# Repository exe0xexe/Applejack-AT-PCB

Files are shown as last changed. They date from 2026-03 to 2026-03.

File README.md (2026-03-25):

# PCB for converting AT layout keyboards to MX
### Powered by QMK/VIAL
## Layout





## Bill Of Materials 

### To build the keyboard, you will need the following materials
- 1x STM32F401CCU6 Blackpill
- Pins and sockets for the microcontrollers (blackpill needs 20 pin stripes)
- 98 1N4148 DO-35 diodes
- 22 Wire jumpers (you can use diode legs) 
- 4 82ohm resistors (optional)
- LED (optional)

## Completed build 

photo_2025-09-02_19-01-52 (2)



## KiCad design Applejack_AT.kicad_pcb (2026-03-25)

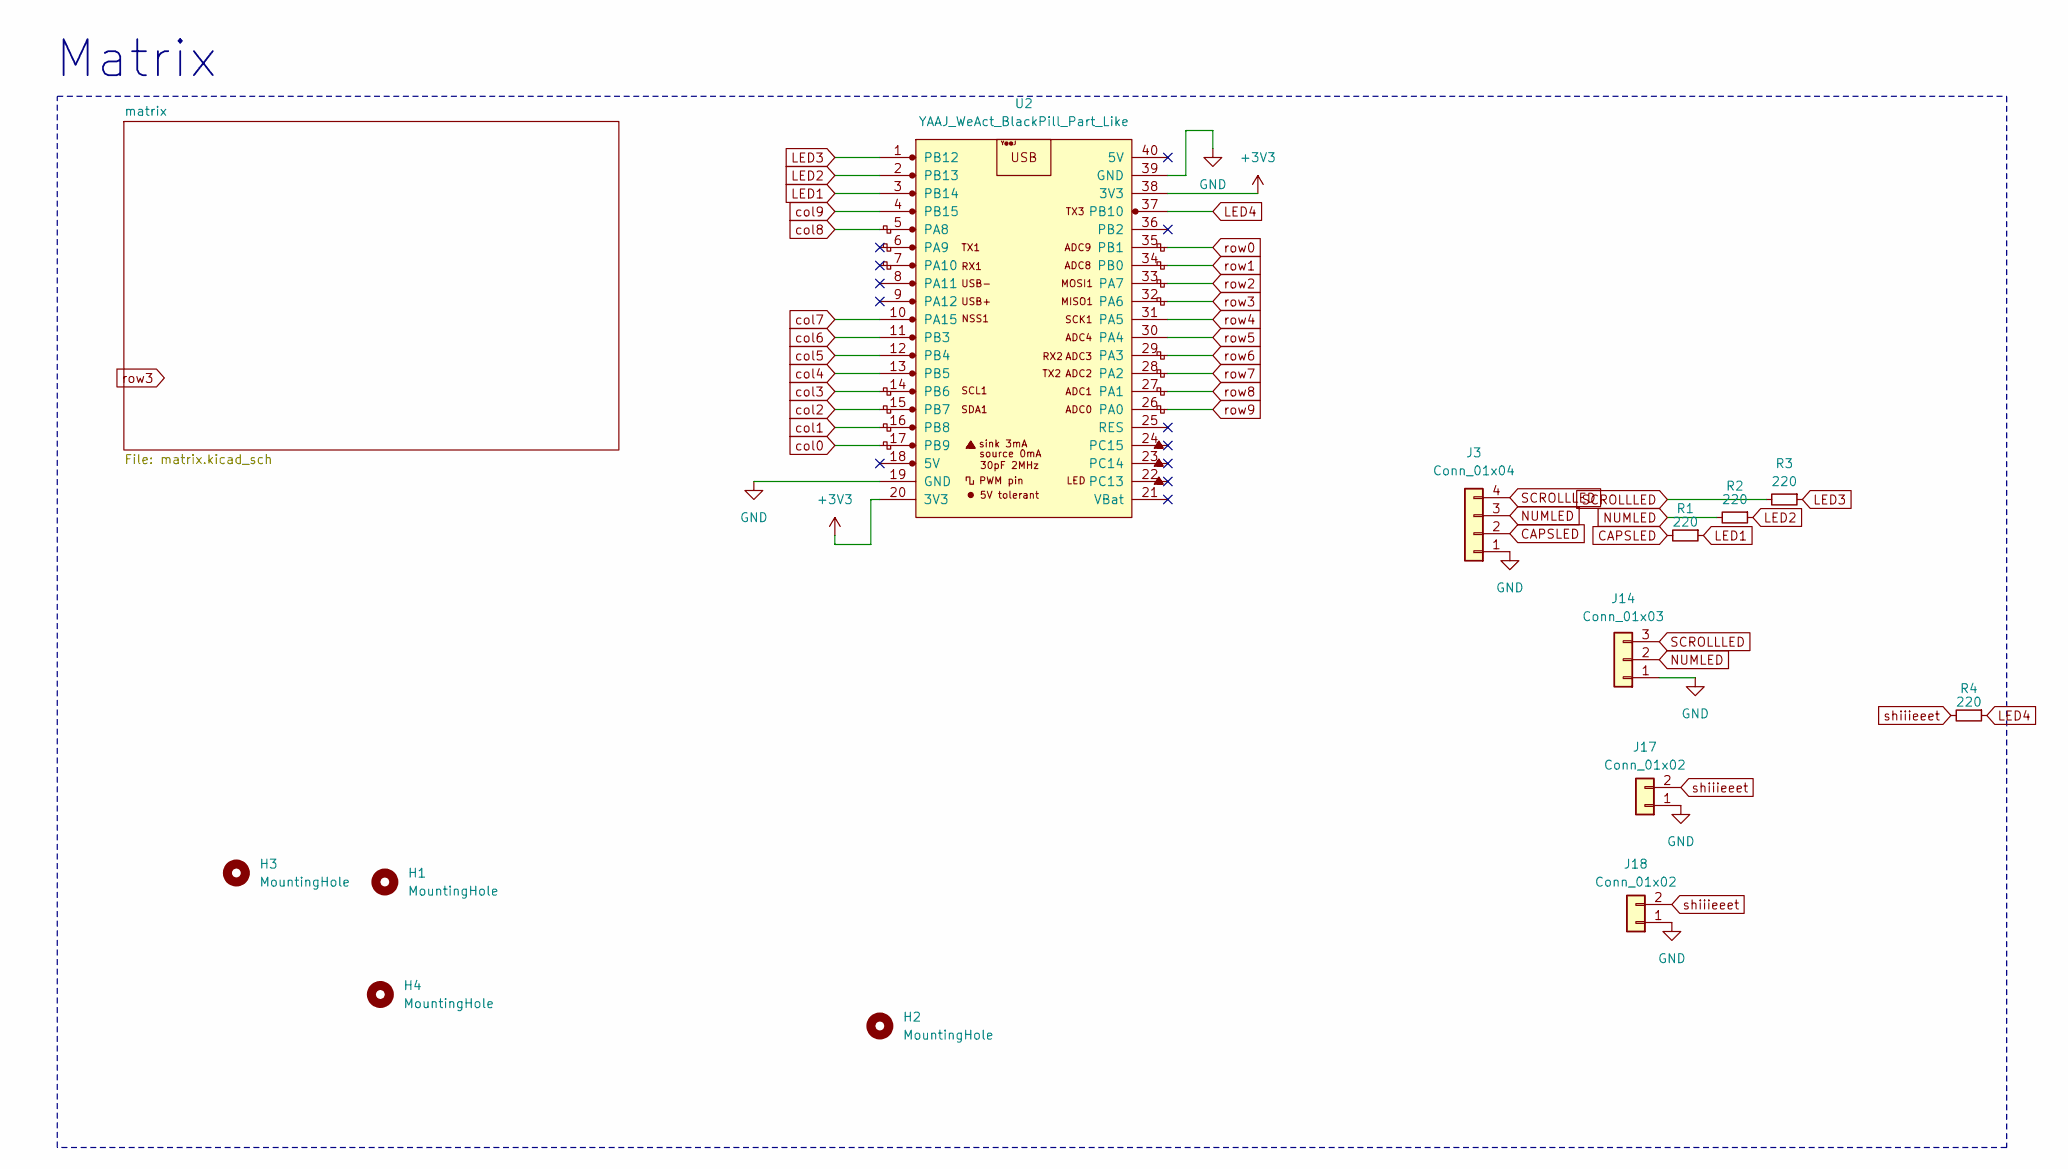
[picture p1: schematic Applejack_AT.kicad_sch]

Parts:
H1, H2, H3, H4: MountingHole; mousebites_2.5mm_4p
J3: Conn_01x04; PinHeader_1x04_P2.54mm_Horizontal
J14: Conn_01x03; 3pin
J17, J18: Conn_01x02; 2pin-GND
R1, R2, R3, R4: 220; R_Axial_DIN0207_L6.3mm_D2.5mm_P7.62mm_Horizontal_no_silkscr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
U2: YAAJ_WeAct_BlackPill_Part_Like; YAAJ_WeAct_BlackPill_2_twilight_sparkle_no_cut

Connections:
+3V3: U2.20 (3V3), U2.38 (3V3)
CAPSLED: J3.2, R1.2; also elsewhere on the board
GND: J3.1, J14.1, J17.1, J18.1, U2.19 (GND), U2.39 (GND); also elsewhere on the board
LED1: R1.1, U2.3 (PB14)
LED2: R2.1, U2.2 (PB13)
LED3: R3.1, U2.1 (PB12)
LED4: R4.1, U2.37 (PB10)
NUMLED: J3.3, J14.2, R2.2; also elsewhere on the board
SCROLLLED: J3.4, J14.3, R3.2; also elsewhere on the board
col0: U2.17 (PB9); also elsewhere on the board
col1: U2.16 (PB8); also elsewhere on the board
col2: U2.15 (PB7); also elsewhere on the board
col3: U2.14 (PB6); also elsewhere on the board
col4: U2.13 (PB5); also elsewhere on the board
col5: U2.12 (PB4); also elsewhere on the board
col6: U2.11 (PB3); also elsewhere on the board
col7: U2.10 (PA15); also elsewhere on the board
col8: U2.5 (PA8); also elsewhere on the board
col9: U2.4 (PB15); also elsewhere on the board
row0: U2.35 (PB1); also elsewhere on the board
row1: U2.34 (PB0); also elsewhere on the board
row2: U2.33 (PA7); also elsewhere on the board
row3: U2.32 (PA6); also elsewhere on the board
row4: U2.31 (PA5); also elsewhere on the board
row5: U2.30 (PA4); also elsewhere on the board
row6: U2.29 (PA3); also elsewhere on the board
row7: U2.28 (PA2); also elsewhere on the board
row8: U2.27 (PA1); also elsewhere on the board
row9: U2.26 (PA0); also elsewhere on the board
shiiieeet: J17.2, J18.2, R4.2; also elsewhere on the board

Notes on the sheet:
Matrix

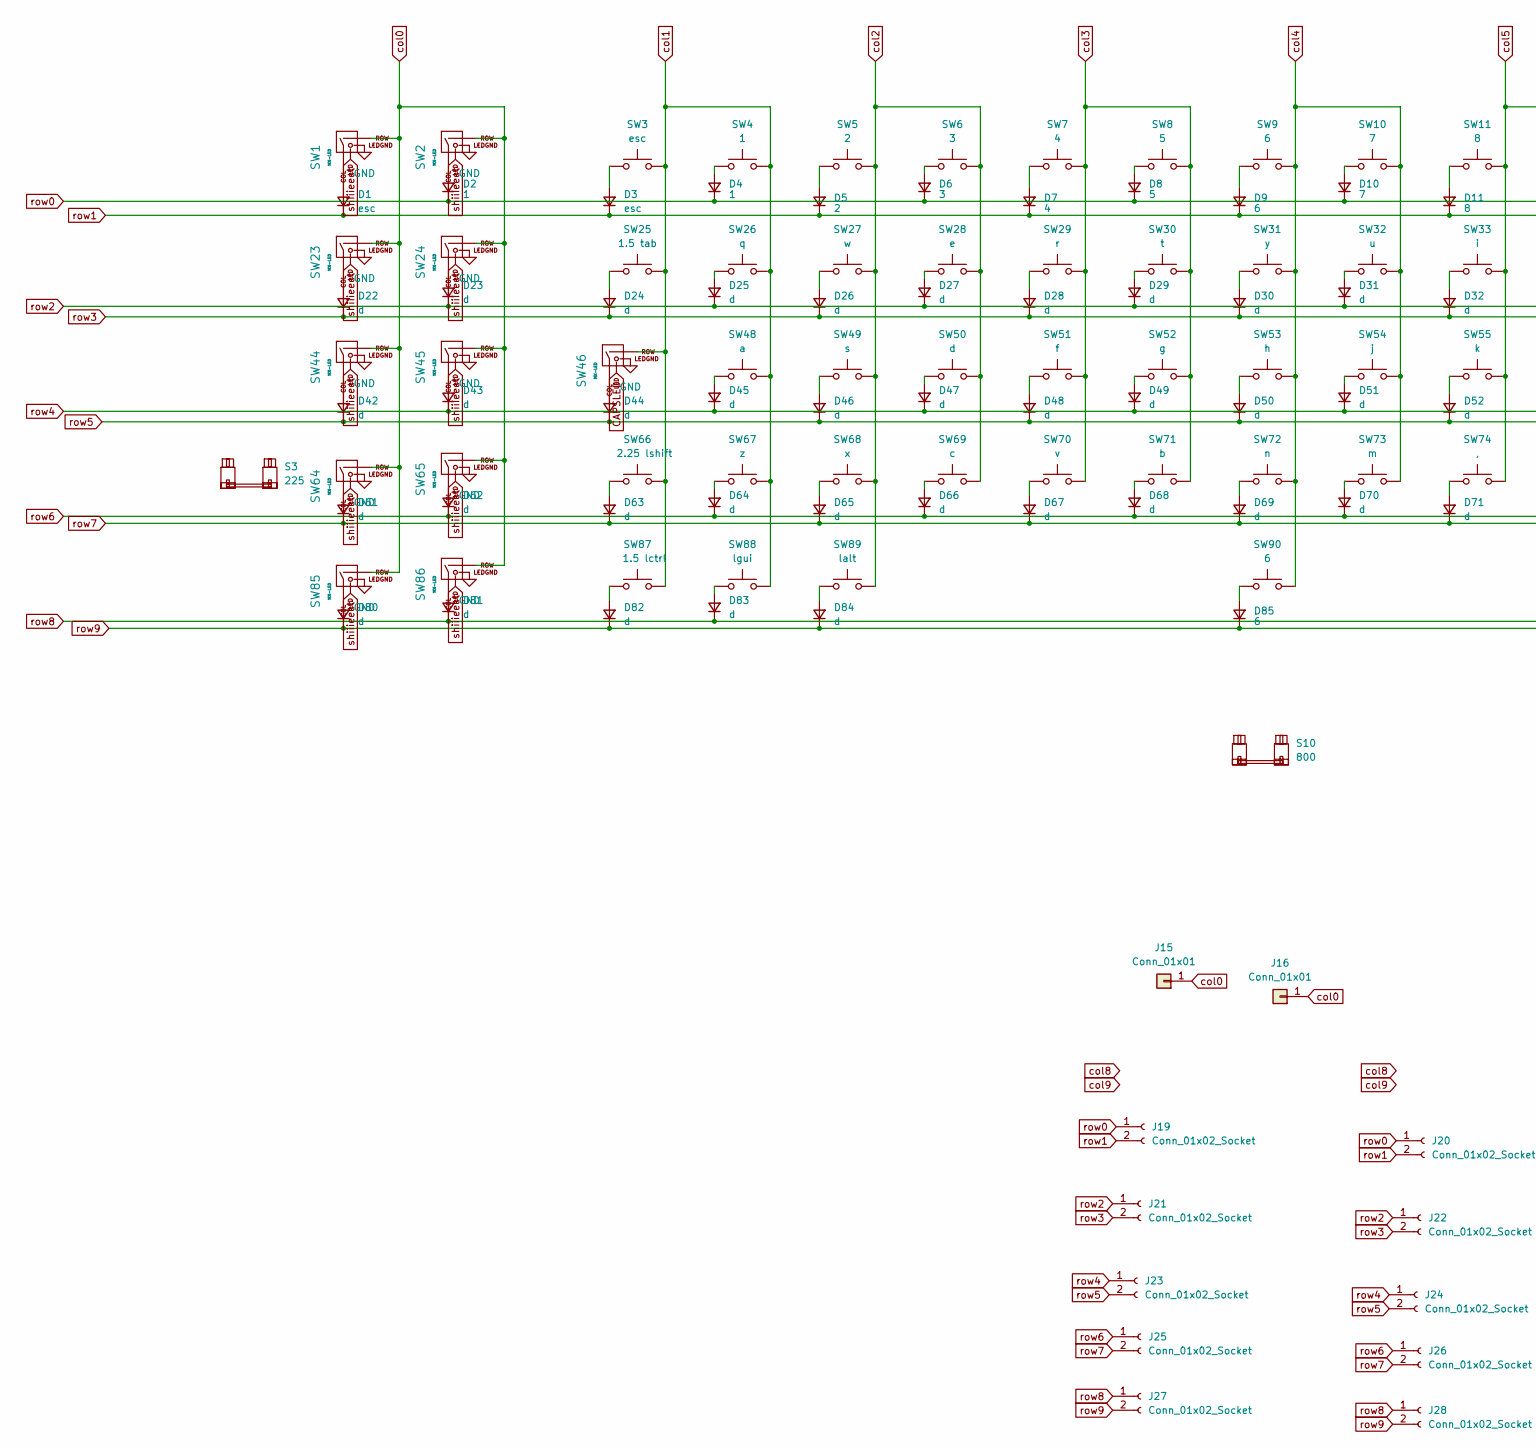
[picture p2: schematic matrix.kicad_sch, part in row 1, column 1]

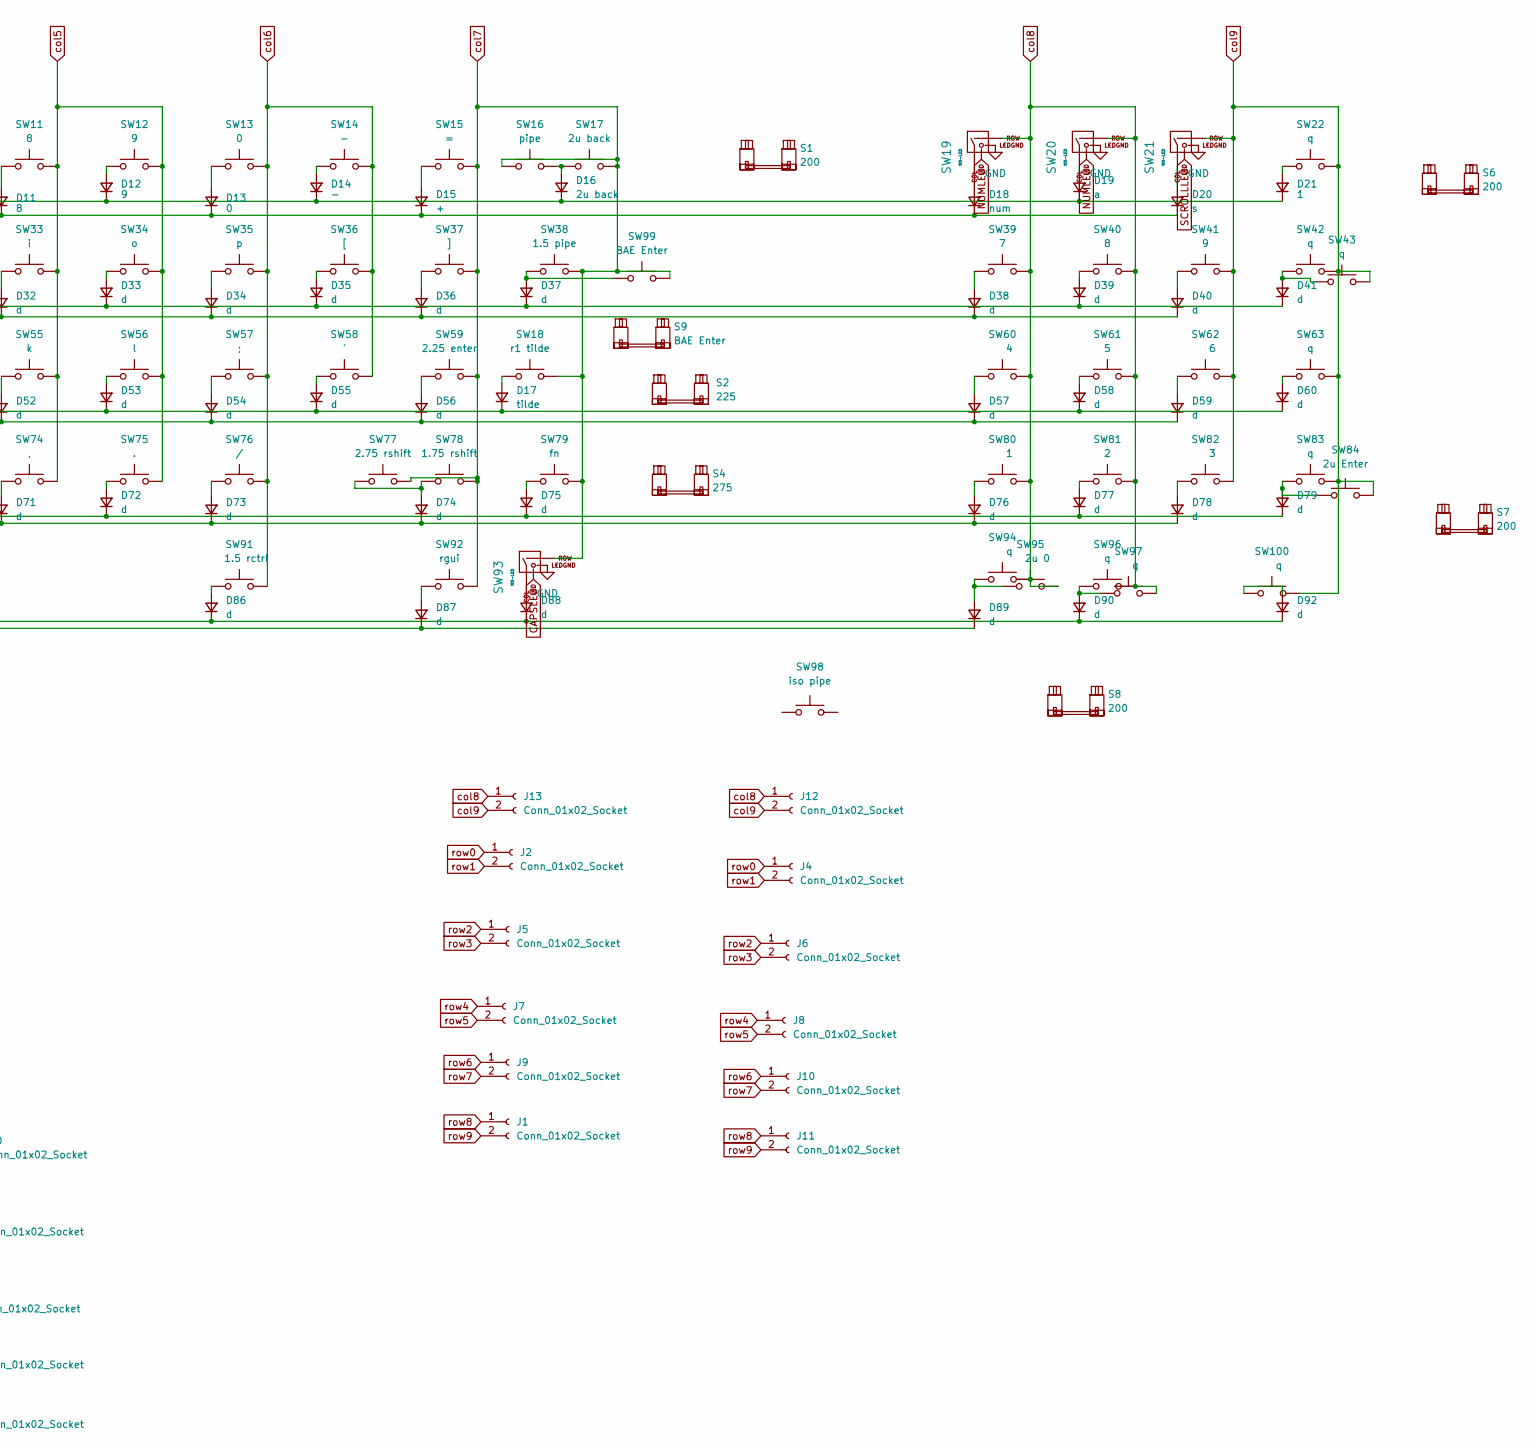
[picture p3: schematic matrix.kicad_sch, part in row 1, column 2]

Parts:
D1, D3: esc; Diode_DO-35
D2, D4, D21: 1; Diode_DO-35
D5: 2; Diode_DO-35
D6: 3; Diode_DO-35
D7: 4; Diode_DO-35
D8: 5; Diode_DO-35
D9, D85: 6; Diode_DO-35
D10: 7; Diode_DO-35
D11: 8; Diode_DO-35
D12: 9; Diode_DO-35
D13: 0; Diode_DO-35
D14: -; Diode_DO-35
D15: +; Diode_DO-35
D16: 2u back; Diode_DO-35
D17: tilde; Diode_DO-35
D18: num; Diode_DO-35
D19: a; Diode_DO-35
D20: s; Diode_DO-35
D22, D23, D24, D25, D26, D27, D28, D29, D30, D31, D32, D33, D34, D35, D36, D37, D38, D39, D40, D41, D42, D43, D44, D45, D46, D47, D48, D49, D50, D51, D52, D53, D54, D55, D56, D57, D58, D59, D60, D61, D62, D63, D64, D65, D66, D67, D68, D69, D70, D71, D72, D73, D74, D75, D76, D77, D78, D79, D80, D81, D82, D83, D84, D86, D87, D88, D89, D90, D92: d; Diode_DO-35
J1, J2, J4, J5, J6, J7, J8, J9, J10, J11, J12, J13, J19, J20, J21, J22, J23, J24, J25, J26, J27, J28: Conn_01x02_Socket; 2pin
J15, J16: Conn_01x01; 1pin
S1, S6, S7, S8: 200; STAB_MX_2u
S2, S3: 225; STAB_MX_2.25u
S4: 275; STAB_MX_2.75u
S9: BAE Enter; STAB_MX_ISO
S10: 800; STAB_MX_10u
SW1, SW2, SW19, SW20, SW21, SW23, SW24, SW44, SW45, SW64, SW65, SW85, SW86, SW93: MX-LED; MX_1U_LED
SW3: esc; MX_1U
SW4, SW80: 1; MX_1U
SW5, SW81: 2; MX_1U
SW6, SW82: 3; MX_1U
SW7, SW60: 4; MX_1U
SW8, SW61: 5; MX_1U
SW9, SW62, SW90: 6; MX_1U
SW10, SW39: 7; MX_1U
SW11, SW40: 8; MX_1U
SW12, SW41: 9; MX_1U
SW13: 0; MX_1U
SW14: -; MX_1U
SW15: =; MX_1U
SW16: pipe; MX_1U
SW17: 2u back; MX_1U
SW18: r1 tilde; MX_1U
SW22, SW26, SW42, SW43, SW63, SW83, SW94, SW96, SW97, SW100: q; MX_1U
SW25: 1.5 tab; MX_1U
SW27: w; MX_1U
SW28: e; MX_1U
SW29: r; MX_1U
SW30: t; MX_1U
SW31: y; MX_1U
SW32: u; MX_1U
SW33: i; MX_1U
SW34: o; MX_1U
SW35: p; MX_1U
SW36: [; MX_1U
SW37: ]; MX_1U
SW38: 1.5 pipe; MX_1U
SW46: MX-LED; MX_CAPS
SW48: a; MX_1U
SW49: s; MX_1U
SW50: d; MX_1U
SW51: f; MX_1U
SW52: g; MX_1U
SW53: h; MX_1U
SW54: j; MX_1U
SW55: k; MX_1U
SW56: l; MX_1U
SW57: ;; MX_1U
SW58: '; MX_1U
SW59: 2.25 enter; MX_1U
SW66: 2.25 lshift; MX_1U
SW67: z; MX_1U
SW68: x; MX_1U
SW69: c; MX_1U
SW70: v; MX_1U
SW71: b; MX_1U
SW72: n; MX_1U
SW73: m; MX_1U
SW74: ,; MX_1U
SW75: .; MX_1U
SW76: /; MX_1U
SW77: 2.75 rshift; MX_1U
SW78: 1.75 rshift; MX_1U
SW79: fn; MX_1U
SW84: 2u Enter; MX_1U
SW87: 1.5 lctrl; MX_1U
SW88: lgui; MX_1U
SW89: lalt; MX_1U
SW91: 1.5 rctrl; MX_1U
SW92: rgui; MX_1U
SW95: 2u 0; MX_1U
SW98: iso pipe; MX_1U
SW99: BAE Enter; MX_1U

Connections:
CAPSLED: SW46.3 (LED), SW93.3 (LED); also elsewhere on the board
GND: SW1.4 (LEDGND), SW2.4 (LEDGND), SW19.4 (LEDGND), SW20.4 (LEDGND), SW21.4 (LEDGND), SW23.4 (LEDGND), SW24.4 (LEDGND), SW44.4 (LEDGND), SW45.4 (LEDGND), SW46.4 (LEDGND), SW64.4 (LEDGND), SW65.4 (LEDGND), SW85.4 (LEDGND), SW86.4 (LEDGND), SW93.4 (LEDGND); also elsewhere on the board
NUMLED: SW19.3 (LED), SW20.3 (LED); also elsewhere on the board
unnamed: D1.2 (A), SW1.1 (COL)
unnamed: D2.2 (A), SW2.1 (COL)
unnamed: D3.2 (A), SW3.1
unnamed: D4.2 (A), SW4.1
unnamed: D5.2 (A), SW5.1
unnamed: D6.2 (A), SW6.1
unnamed: D7.2 (A), SW7.1
unnamed: D8.2 (A), SW8.1
unnamed: D9.2 (A), SW9.1
unnamed: D10.2 (A), SW10.1
unnamed: D11.2 (A), SW11.1
unnamed: D12.2 (A), SW12.1
unnamed: D13.2 (A), SW13.1
unnamed: D14.2 (A), SW14.1
unnamed: D15.2 (A), SW15.1
unnamed: D16.2 (A), SW16.1, SW17.1
unnamed: D17.2 (A), SW18.1
unnamed: D18.2 (A), SW19.1 (COL)
unnamed: D19.2 (A), SW20.1 (COL)
unnamed: D20.2 (A), SW21.1 (COL)
unnamed: D21.2 (A), SW22.1
unnamed: D22.2 (A), SW23.1 (COL)
unnamed: D23.2 (A), SW24.1 (COL)
unnamed: D24.2 (A), SW25.1
unnamed: D25.2 (A), SW26.1
unnamed: D26.2 (A), SW27.1
unnamed: D27.2 (A), SW28.1
unnamed: D28.2 (A), SW29.1
unnamed: D29.2 (A), SW30.1
unnamed: D30.2 (A), SW31.1
unnamed: D31.2 (A), SW32.1
unnamed: D32.2 (A), SW33.1
unnamed: D33.2 (A), SW34.1
unnamed: D34.2 (A), SW35.1
unnamed: D35.2 (A), SW36.1
unnamed: D36.2 (A), SW37.1
unnamed: D37.2 (A), SW38.1, SW99.1
unnamed: D38.2 (A), SW39.1
unnamed: D39.2 (A), SW40.1
unnamed: D40.2 (A), SW41.1
unnamed: D41.2 (A), SW42.1, SW43.1
unnamed: D42.2 (A), SW44.1 (COL)
unnamed: D43.2 (A), SW45.1 (COL)
unnamed: D44.2 (A), SW46.1 (COL)
unnamed: D45.2 (A), SW48.1
unnamed: D46.2 (A), SW49.1
unnamed: D47.2 (A), SW50.1
unnamed: D48.2 (A), SW51.1
unnamed: D49.2 (A), SW52.1
unnamed: D50.2 (A), SW53.1
unnamed: D51.2 (A), SW54.1
unnamed: D52.2 (A), SW55.1
unnamed: D53.2 (A), SW56.1
unnamed: D54.2 (A), SW57.1
unnamed: D55.2 (A), SW58.1
unnamed: D56.2 (A), SW59.1
unnamed: D57.2 (A), SW60.1
unnamed: D58.2 (A), SW61.1
unnamed: D59.2 (A), SW62.1
unnamed: D60.2 (A), SW63.1
unnamed: D61.2 (A), SW64.1 (COL)
unnamed: D62.2 (A), SW65.1 (COL)
unnamed: D63.2 (A), SW66.1
unnamed: D64.2 (A), SW67.1
unnamed: D65.2 (A), SW68.1
unnamed: D66.2 (A), SW69.1
unnamed: D67.2 (A), SW70.1
unnamed: D68.2 (A), SW71.1
unnamed: D69.2 (A), SW72.1
unnamed: D70.2 (A), SW73.1
unnamed: D71.2 (A), SW74.1
unnamed: D72.2 (A), SW75.1
unnamed: D73.2 (A), SW76.1
unnamed: D74.2 (A), SW77.1, SW78.1
unnamed: D75.2 (A), SW79.1
unnamed: D76.2 (A), SW80.1
unnamed: D77.2 (A), SW81.1
unnamed: D78.2 (A), SW82.1
unnamed: D79.2 (A), SW83.1, SW84.1
unnamed: D80.2 (A), SW85.1 (COL)
unnamed: D81.2 (A), SW86.1 (COL)
unnamed: D82.2 (A), SW87.1
unnamed: D83.2 (A), SW88.1
unnamed: D84.2 (A), SW89.1
unnamed: D85.2 (A), SW90.1
unnamed: D86.2 (A), SW91.1
unnamed: D87.2 (A), SW92.1
unnamed: D88.2 (A), SW93.1 (COL)
unnamed: D89.2 (A), SW94.1, SW95.1
unnamed: D90.2 (A), SW96.1, SW97.1
unnamed: D92.2 (A), SW100.1
SCROLLLED: SW21.3 (LED); also elsewhere on the board
col0: J15.1, J16.1, SW1.2 (ROW), SW2.2 (ROW), SW23.2 (ROW), SW24.2 (ROW), SW44.2 (ROW), SW45.2 (ROW), SW64.2 (ROW), SW65.2 (ROW), SW85.2 (ROW), SW86.2 (ROW); also elsewhere on the board
col1: SW3.2, SW4.2, SW25.2, SW26.2, SW46.2 (ROW), SW48.2, SW66.2, SW67.2, SW87.2, SW88.2; also elsewhere on the board
col2: SW5.2, SW6.2, SW27.2, SW28.2, SW49.2, SW50.2, SW68.2, SW69.2, SW89.2; also elsewhere on the board
col3: SW7.2, SW8.2, SW29.2, SW30.2, SW51.2, SW52.2, SW70.2, SW71.2; also elsewhere on the board
col4: SW9.2, SW10.2, SW31.2, SW32.2, SW53.2, SW54.2, SW72.2, SW73.2, SW90.2; also elsewhere on the board
col5: SW11.2, SW12.2, SW33.2, SW34.2, SW55.2, SW56.2, SW74.2, SW75.2; also elsewhere on the board
col6: SW13.2, SW14.2, SW35.2, SW36.2, SW57.2, SW58.2, SW76.2, SW91.2; also elsewhere on the board
col7: SW15.2, SW16.2, SW17.2, SW18.2, SW37.2, SW38.2, SW59.2, SW77.2, SW78.2, SW79.2, SW92.2, SW93.2 (ROW), SW99.2; also elsewhere on the board
col8: J12.1, J13.1, SW19.2 (ROW), SW20.2 (ROW), SW39.2, SW40.2, SW60.2, SW61.2, SW80.2, SW81.2, SW94.2, SW95.2, SW96.2, SW97.2; also elsewhere on the board
col9: J12.2, J13.2, SW21.2 (ROW), SW22.2, SW41.2, SW42.2, SW43.2, SW62.2, SW63.2, SW82.2, SW83.2, SW84.2, SW100.2; also elsewhere on the board
row0: D2.1 (K), D4.1 (K), D6.1 (K), D8.1 (K), D10.1 (K), D12.1 (K), D14.1 (K), D16.1 (K), D19.1 (K), D21.1 (K), J2.1, J4.1, J19.1, J20.1; also elsewhere on the board
row1: D1.1 (K), D3.1 (K), D5.1 (K), D7.1 (K), D9.1 (K), D11.1 (K), D13.1 (K), D15.1 (K), D18.1 (K), D20.1 (K), J2.2, J4.2, J19.2, J20.2; also elsewhere on the board
row2: D23.1 (K), D25.1 (K), D27.1 (K), D29.1 (K), D31.1 (K), D33.1 (K), D35.1 (K), D37.1 (K), D39.1 (K), D41.1 (K), J5.1, J6.1, J21.1, J22.1; also elsewhere on the board
row3: D22.1 (K), D24.1 (K), D26.1 (K), D28.1 (K), D30.1 (K), D32.1 (K), D34.1 (K), D36.1 (K), D38.1 (K), D40.1 (K), J5.2, J6.2, J21.2, J22.2; also elsewhere on the board
row4: D17.1 (K), D43.1 (K), D45.1 (K), D47.1 (K), D49.1 (K), D51.1 (K), D53.1 (K), D55.1 (K), D58.1 (K), D60.1 (K), J7.1, J8.1, J23.1, J24.1; also elsewhere on the board
row5: D42.1 (K), D44.1 (K), D46.1 (K), D48.1 (K), D50.1 (K), D52.1 (K), D54.1 (K), D56.1 (K), D57.1 (K), D59.1 (K), J7.2, J8.2, J23.2, J24.2; also elsewhere on the board
row6: D62.1 (K), D64.1 (K), D66.1 (K), D68.1 (K), D70.1 (K), D72.1 (K), D75.1 (K), D77.1 (K), D79.1 (K), J9.1, J10.1, J25.1, J26.1; also elsewhere on the board
row7: D61.1 (K), D63.1 (K), D65.1 (K), D67.1 (K), D69.1 (K), D71.1 (K), D73.1 (K), D74.1 (K), D76.1 (K), D78.1 (K), J9.2, J10.2, J25.2, J26.2; also elsewhere on the board
row8: D81.1 (K), D83.1 (K), D86.1 (K), D88.1 (K), D90.1 (K), D92.1 (K), J1.1, J11.1, J27.1, J28.1; also elsewhere on the board
row9: D80.1 (K), D82.1 (K), D84.1 (K), D85.1 (K), D87.1 (K), D89.1 (K), J1.2, J11.2, J27.2, J28.2; also elsewhere on the board
shiiieeet: SW1.3 (LED), SW2.3 (LED), SW23.3 (LED), SW24.3 (LED), SW44.3 (LED), SW45.3 (LED), SW64.3 (LED), SW65.3 (LED), SW85.3 (LED), SW86.3 (LED); also elsewhere on the board

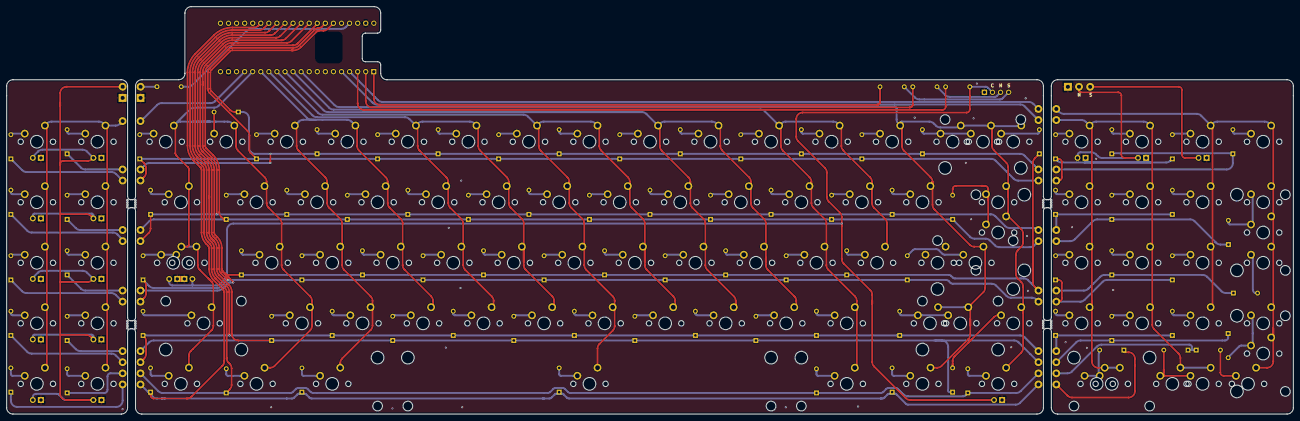
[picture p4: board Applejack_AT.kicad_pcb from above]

Board: 2 copper layers, 404.9 x 128.2 mm, 236 parts (1 on the bottom side), 121 nets.
